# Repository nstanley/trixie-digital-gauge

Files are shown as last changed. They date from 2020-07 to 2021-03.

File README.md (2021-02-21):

# trixie-digital-gauge
A digital OBD-II gauge for my 2001 Audi TT, Trixie!

## Overview
I've wanted to do an On Board Diagnostics project for a while, just for the sake of seeing some of the data my car knows but I don't. I've deployed this to my project/fun car, a 2001 Audi TT.  
When the car is turned on, the Raspberry Pi is powered on and it runs the appropriate python script. The user can cycle through the available data via a rotary encoder. Once the car is powered off, the Raspberry Pi will shutdown automatically, waiting for the next ignition.

## Hardware
Most aftermarked car gauges come in a 52mm package, so that was my target for selecting a screen. There are probably screens that will fit in a 52mm diameter, however with the extra pins and mount points, I ended up with a 57mm sized gauge (57mm is the size of the climate control dials). 
 * For the screen, I chose Adafruit's [OLED Breakout Board - 16-bit Color 1.27" w/microSD holder](https://www.adafruit.com/product/1673), which is large enough to be easily visible and small enough to fit my 57mm gauge. 
 * For control, I chose a Raspberry Pi Zero. Running a Linux OS instead of directly on a board was just a faster way to get all my components together.
 * To interface to the car, I have a USB ELM327 
 * To cycle between PIDs, I'm using a rotary encoder
 * To power the board in the car, I'm using [Mausberry's 4AMP CAR SUPPLY / SWITCH](https://mausberry-circuits.myshopify.com/collections/frontpage/products/4amp-car-supply-switch). This is a pretty slick board that attaches to the car's 12V feeds, both constant and switched, to check if the car is on and send power accordingly

## Software
As a C/C++ guy, I chose Python for this project. Why? Primarily because there are tons of existing libraries out there to do what I need done. Those libraries primarily being [Adafruit's](https://learn.adafruit.com/adafruit-1-5-color-oled-breakout-board?view=all) to control their OLED and [python-OBD](https://python-obd.readthedocs.io/en/latest/) to interface with the ELM327 over USB.
The software is setup with a Model-View-Controller pattern. The controller `trixie.py` creates a model `trixie-model.py` to get the data from the ELM327. The controller then pipes that data to the view `trixie-view.py`, which manages the OLED to display the data. This decouples the logic so I can swap in different models or different views (see Future Work below) with ease.

## Setup
As I looked for the fastest way to boot a Raspberry Pi, I came across [DietPi](https://dietpi.com/). I'm always looking for different Linux distros, so I gave it a shot. 

### OS Setup
I used [DietPi's Raspberry Pi 32 bit image](https://dietpi.com/downloads/images/DietPi_RPi-ARMv6-Buster.7z) and [Balena's Etcher](https://www.balena.io/etcher/) software to flash an 8GB SD card. Before you install the SD card, you will need to edit the `/boot/config.txt` to enable SPI, as DietPi does not have an option to do that internally. Edit the SPI line as shown below
```
#-------SPI-------------
dtparam=spi=on
```
Once booted and logged in (I logged in as `root`), DietPi should ask you to configure your setup, which you can access via
```
dietpi-config
```
If your network wasn't setup on first boot, it will probably complain about trying to connect to the network. Use `DietPi-Config` to configure the network setup, then `Retry` so it can pull the latest updates. The setup will ask some questions, and eventually end on a page about installing additional software. You can just hit `<OK>` at the bottom, and confirm you want to start with a minimal image. Once finished, you can configure the following options for fast boot and our startup from `DietPi-Config`.
 * Advanced Options-> Time sync mode -> Custom. No need to sync the clock, the time sync requires internet to sync and we won't always have it in the car. And this will block the boot sequence
 * Network Options: Misc -> Boot Net Wait -> Disabled. 
 * AutoStart Options -> Custom. We will use a script to launch our app.

Now we just need `git` to grab the repo
```
sudo apt install git
```
We can now setup the software

### Software Setup
The first step would be to clone this repo
```
git clone https://github.com/nstanley/trixie-digital-gauge.git
cd trixie-digital-gauge
```
To get all the necessary libraries, you can use the `get-deps.sh` script
```
sudo bash get-deps.sh
```
This will install support packages used by the gauge. You should now be able to run the gauge
```
python3 code/trixie.py
```
If you don't have this wired in the car, it should attempt to connect to the car, fail 7 times, then run a simple demo. If you see `Demo: Connected!` and it is still running, then everything is installed and setup.

The final step is to setup the autostart script. I have setup a necessary script at `resources/autostart.sh`
```
cp resources/autostart.sh /var/lib/dietpi/dietpi-autostart/custom.sh
chmod 777 /var/lib/dietpi/dietpi-autostart/custom.sh
```
Final check - reboot and verify the same output as the initial test above, but from the start without any user interaction. The demo is set to run for a short time and then stop, which would send the script to the following `poweroff` command (assuming this was in a car, we shutdown once we exit the gauge).

### Hardware setup

### Future work
I came across an awesome [Hackster.io post](https://www.hackster.io/databus100/digital-speedometer-to-car-s-instrument-cluster-via-can-bus-66e273) about sending data to the existing LCD screen in the TT, as if it were the radio. The Hackster post describes a system with the "new" CAN interface, but I'm lucky enough to have the earlier interface described by the [inspiration for the post](https://github.com/derpston/Audi-radio-DIS-reader). I have parts on order to try to tap into that interface.

## Resources
 * https://en.wikipedia.org/wiki/OBD-II_PIDs
 * https://python-obd.readthedocs.io/en/latest/
 * https://github.com/guyc/py-gaugette
 * https://learn.adafruit.com/circuitpython-on-raspberrypi-linux/spi-sensors-devices
 * https://learn.adafruit.com/adafruit-1-5-color-oled-breakout-board?view=all
 * https://learn.adafruit.com/reading-a-analog-in-and-controlling-audio-volume-with-the-raspberry-pi?view=all
 * https://www.dafont.com/seven-segment.font

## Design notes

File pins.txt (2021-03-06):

        Pwr   - xx - 
              - xx - 
              - xx - Gnd
              - xx - 
Btn Gray      - xx - 
              - xx - 
Btn Purp      - xx - 
Btn Blue      - xx - 
              - xx - Scr Purp (R)
Scr Yllw (SI) - xx - 
              - xx - Scr Blue (DC)
Scr Gren (CL) - xx - scr Gray (OC/CE0)
              - xx - 
              - xx - 
              - xx - 
              - xx - 
              - xx - 
Btn Purp (B)  - xx - 
Btn Blue (A)  - xx - 
Btn Gray      - xx - 

+-----+-----+---------+------+---+---Pi 3---+---+------+---------+-----+-----+
 | BCM | wPi |   Name  | Mode | V | Physical | V | Mode | Name    | wPi | BCM |
 +-----+-----+---------+------+---+----++----+---+------+---------+-----+-----+
 |     |     |    3.3v |      |   |  1 || 2  |   |      | 5v      |     |     |
 |   2 |   8 |   SDA.1 | ALT0 | 1 |  3 || 4  |   |      | 5v      |     |     |
 |   3 |   9 |   SCL.1 | ALT0 | 1 |  5 || 6  |   |      | 0v      |     |     |
 |   4 |   7 | GPIO. 7 |   IN | 1 |  7 || 8  | 0 | IN   | TxD     | 15  | 14  |
 |     |     |      0v |      |   |  9 || 10 | 1 | IN   | RxD     | 16  | 15  |
 |  17 |   0 | GPIO. 0 |   IN | 0 | 11 || 12 | 0 | IN   | GPIO. 1 | 1   | 18  |
 |  27 |   2 | GPIO. 2 |   IN | 0 | 13 || 14 |   |      | 0v      |     |     |
 |  22 |   3 | GPIO. 3 |   IN | 0 | 15 || 16 | 0 | IN   | GPIO. 4 | 4   | 23  |
 |     |     |    3.3v |      |   | 17 || 18 | 0 | IN   | GPIO. 5 | 5   | 24  |
 |  10 |  12 |    MOSI | ALT0 | 0 | 19 || 20 |   |      | 0v      |     |     |
 |   9 |  13 |    MISO | ALT0 | 0 | 21 || 22 | 0 | IN   | GPIO. 6 | 6   | 25  |
 |  11 |  14 |    SCLK | ALT0 | 0 | 23 || 24 | 1 | OUT  | CE0     | 10  | 8   |
 |     |     |      0v |      |   | 25 || 26 | 1 | OUT  | CE1     | 11  | 7   |
 |   0 |  30 |   SDA.0 |   IN | 1 | 27 || 28 | 1 | IN   | SCL.0   | 31  | 1   |
 |   5 |  21 | GPIO.21 |   IN | 1 | 29 || 30 |   |      | 0v      |     |     |
 |   6 |  22 | GPIO.22 |   IN | 1 | 31 || 32 | 0 | IN   | GPIO.26 | 26  | 12  |
 |  13 |  23 | GPIO.23 |   IN | 0 | 33 || 34 |   |      | 0v      |     |     |
 |  19 |  24 | GPIO.24 |   IN | 0 | 35 || 36 | 0 | IN   | GPIO.27 | 27  | 16  |
 |  26 |  25 | GPIO.25 |   IN | 0 | 37 || 38 | 0 | IN   | GPIO.28 | 28  | 20  |
 |     |     |      0v |      |   | 39 || 40 | 0 | IN   | GPIO.29 | 29  | 21  |
 +-----+-----+---------+------+---+----++----+---+------+---------+-----+-----+
 | BCM | wPi |   Name  | Mode | V | Physical | V | Mode | Name    | wPi | BCM |
 +-----+-----+---------+------+---+---Pi 3---+---+------+---------+-----+-----+

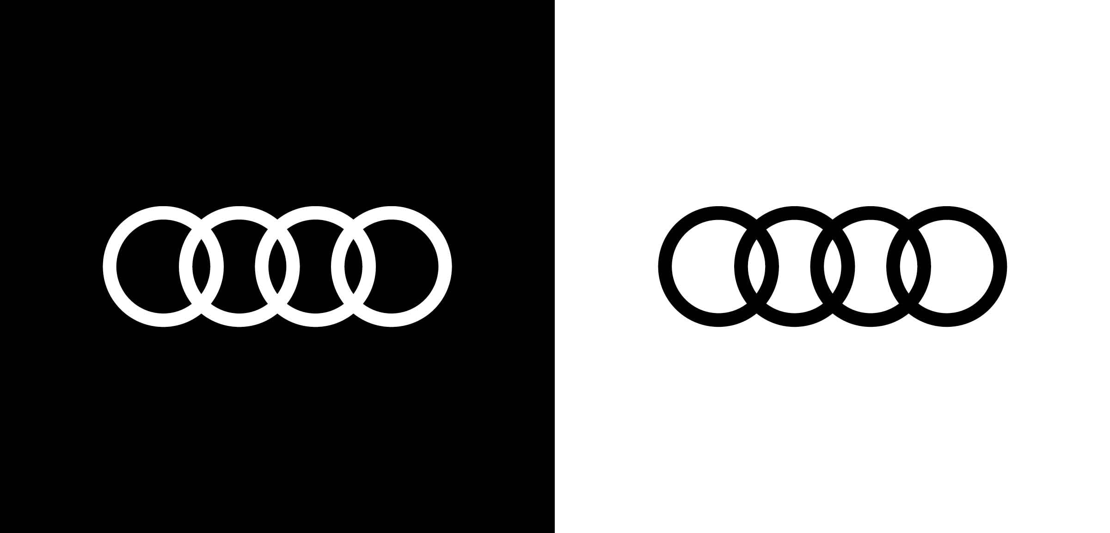
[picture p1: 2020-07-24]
resources/Audi_Brandplattform_Ringe_Content1.jpg

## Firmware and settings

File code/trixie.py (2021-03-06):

# Main program to run the OBD Gauge

import os
import time
import subprocess
import digitalio
import board
import gaugette.gpio
import gaugette.rotary_encoder
import gaugette.switch
import json
import enum

from trixie_view import TrixieView_OLED, TrixieView_DIS
from trixie_model import TrixieModel, TrixieModel_OBD, TrixieModel_Demo

# Configuration for CS and DC pins (these are PiTFT defaults):
cs_pin = digitalio.DigitalInOut(board.CE0)
dc_pin = digitalio.DigitalInOut(board.D25)
reset_pin = digitalio.DigitalInOut(board.D24)

# Config for display baudrate (default max is 24mhz):
BAUDRATE = 24000000

# Splash Image
BASE_DIR = os.path.dirname(os.path.dirname(os.path.abspath(__file__)))
splashFile = BASE_DIR + "/resources/audi_128x96-big-red.png"

# Rotary encoder pins (WiringPi numbering)
enc_A_pin = 23
enc_B_pin = 24
enc_btn_pin = 25

# Radio display pins (WiringPi numbering)
dis_clk_pin = 27
dis_data_pin = 28
dis_enable_pin = 29

class Mode(str, enum.Enum):
    ControlGauge = "ControlGauge"
    ControlRadio = "ControlRadio"
    ControlNone = "ControlNone"

class TrixieController():
    def __init__(self):
        # Setup VIEW
        self.viewGauge = TrixieView_OLED(cs_pin, dc_pin, reset_pin, BAUDRATE, splashFile)
        self.viewRadio = TrixieView_DIS(dis_clk_pin, dis_data_pin, dis_enable_pin, 1)
    
        # Setup MODEL
        self.modelDemo = TrixieModel_Demo()
        self.modelOBD = TrixieModel_OBD()
        self.model = self.modelOBD

        # Connect
        if (self.model.connect("/dev/ttyUSB0", 7)):
            self.demo = False
            print("Connected!")
        else:
            self.demo = True
            self.startTime = time.perf_counter()
            print("OBD Timeout, switch to DEMO MODE!")
            self.model = self.modelDemo
            self.model.connect("/dev/ttyAMA0", 7)

        # Setup list
        self.labels = ("Eng Load",
                       "Cool Tmp",
                       "S Fuel",
                       "L Fuel",
                       "RPM",
                       "Speed",
                       "Intake Tmp",
                       "MAF",
                       "Throttle")
        self.values = (self.model.getEngineLoad,
                       self.model.getEngineTemp,
                       self.model.getShortFuelTrim,
                       self.model.getLongFuelTrim,
                       self.model.getRPM,
                       self.model.getSpeed,
                       self.model.getIntakeTemp,
                       self.model.getMAF,
                       self.model.getThrottle)
        self.load()
        
        # Setup rotary encoder
        gpio = gaugette.gpio.GPIO()
        self.encoder = gaugette.rotary_encoder.RotaryEncoder(gpio, enc_A_pin, enc_B_pin, self.rotated)
        self.encoder.start()
        self.button = gaugette.switch.Switch(gpio, enc_btn_pin)
        self.button.enable_isr(gpio.EDGE_FALLING, self.pushed)

    def run(self):
        running = True
        while (running):
            try:
                self.viewGauge.showData(self.labels[self.gaugeIndex], str(self.values[self.gaugeIndex]()))
                if (self.radioIndex >= len(self.labels)):
                    self.viewRadio.showData("", "")
                else:
                    self.viewRadio.showData(self.labels[self.radioIndex], str(self.values[self.radioIndex]()))
                time.sleep(0.2)
            except:
                running = False

            # Only run the demo for 64s
            if self.demo:
                now = time.perf_counter()
                diff = now - self.startTime
                if (diff > 64):
                    running = False
        self.save()
        exit()
    
    # ISR for rotary encoder
    def rotated(self, direction):
        if (self.modeIndex == Mode.ControlGauge):
            self.gaugeIndex += direction
            if (self.gaugeIndex >= len(self.labels)):
                self.gaugeIndex = 0
            if (self.gaugeIndex < 0):
                self.gaugeIndex = len(self.labels) - 1
        elif (self.modeIndex == Mode.ControlRadio):
            self.radioIndex += direction
            if (self.radioIndex > len(self.labels)): # additional index for off
                self.radioIndex = 0
            if (self.radioIndex < 0):
                self.radioIndex = len(self.labels)

    def pushed(self):
        if (self.modeIndex == Mode.ControlGauge):
            self.modeIndex = Mode.ControlRadio
        elif (self.modeIndex == Mode.ControlRadio):
            self.modeIndex = Mode.ControlNone
        elif (self.modeIndex == Mode.ControlNone):
            self.modeIndex = Mode.ControlGauge

    def save(self):
        data = {}
        data['save'] = []
        data['save'].append(
            {
                'gaugeIndex': self.gaugeIndex,
                'radioIndex': self.radioIndex,
                'modeIndex': self.modeIndex
            }
        )
        with open('save.json', 'w') as filePtr:
            json.dump(data, filePtr)

    def load(self):
        try:
            with open('save.json', 'r') as filePtr:
                saveData = json.load(filePtr)
                for d in saveData['save']:
                    self.gaugeIndex = d['gaugeIndex']
                    self.radioIndex = d['radioIndex']
                    self.modeIndex = d['modeIndex']
        except:
            self.gaugeIndex = 0
            self.radioIndex = 0
            self.modeIndex = Mode.ControlNone

def main():
    print("Trixie Digital Gauge Startup!")
    gauge = TrixieController()
    gauge.run()

if __name__ == "__main__":
    main()

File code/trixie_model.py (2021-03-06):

import time
import random
import obd
from obd import OBDStatus
from obd import OBDCommand, Unit
from obd.protocols import ECU
from obd.utils import bytes_to_int

class TrixieModel():
    def __init__(self):
        print("baseclass")

    def getEngineLoad(self):
        return 0

    def getEngineTemp(self):
        return 0

    def getShortFuelTrim(self):
        return 0

    def getLongFuelTrim(self):
        return 0

    def getRPM(self):
        return 0
    def getSpeed(self):
        return 0

    def getIntakeTemp(self):
        return 0

    def getMAF(self):
        return 0

    def getThrottle(self):
        return 0

class TrixieModel_OBD(TrixieModel):
    def __init__(self):
        print("OBD: OBD model initialized")

    def connect(self, address, max_attempts):
        print("OBD: Attempting OBD-II connection...")
        self.connection = obd.OBD(address)
        attempts = 0
        # Attempt retries as necessary
        while (self.connection.status() != OBDStatus.CAR_CONNECTED and attempts < max_attempts):
            attempts += 1
            print("OBD: Attempting reconnect", attempts, "...")
            time.sleep(1)
            self.connection = obd.OBD(address)

        if (self.connection.status() != OBDStatus.CAR_CONNECTED):
            print("OBD: Could not connect after", attempts, "retries!")
            self.connection.close()
            return False
        else:
            print("OBD: Connected!")
            return True

    def getEngineLoad(self):
        retrun = self.connection.query(obd.commands.ENGINE_LOAD)
        return '{:d}'.format(int(retrun.value.magnitude))

    def getEngineTemp(self):
        retrun = self.connection.query(obd.commands.COOLANT_TEMP)
        return '{:d}'.format(int(retrun.value.to('degF').magnitude))

    def getShortFuelTrim(self):
        retrun = self.connection.query(obd.commands.SHORT_FUEL_TRIM_1)
        return '{:.2f}'.format(retrun.value.magnitude)

    def getLongFuelTrim(self):
        retrun = self.connection.query(obd.commands.LONG_FUEL_TRIM_1)
        return '{:.2f}'.format(retrun.value.magnitude)

    def getRPM(self):
        retrun = self.connection.query(obd.commands.RPM)
        return '{:d}'.format(int(retrun.value.magnitude))

    def getSpeed(self):
        retrun = self.connection.query(obd.commands.SPEED)
        return '{:d}'.format(int(retrun.value.to('mph').magnitude))

    def getIntakeTemp(self):
        retrun = self.connection.query(obd.commands.INTAKE_TEMP)
        return '{:d}'.format(int(retrun.value.to('degF').magnitude))

    def getMAF(self):
        retrun = self.connection.query(obd.commands.MAF)
        return '{:.1f}'.format(retrun.value.magnitude)

    def getThrottle(self):
        retrun = self.connection.query(obd.commands.THROTTLE_POS)
        return '{:d}'.format(int(retrun.value.magnitude))

class TrixieModel_Demo(TrixieModel):
    def __init__(self):
        print("Demo: Demo model initialized!")
        self.engine_load = 0
        self.engine_temp = 0
        self.short_fuel = 0
        self.long_fuel = 0
        self.RPM = 0
        self.speed = 0
        self.intake_temp = 0
        self.MAF = 0
        self.throttle = 0

    def connect(self, address, max_attempts):
        print("Demo: Attempting OBD-II connection...")
        time.sleep(1.0)
        print("Demo: Connected!")
        return True

    def getEngineLoad(self):
        if (self.engine_load > 50):
            new_load = self.engine_load + random.randint(-7, 3)
        else:
            new_load = self.engine_load + random.randint(-3, 7)
            
        if (new_load < 0):
            new_load = 0
        if (new_load > 100):
            new_load = 100

        self.engine_load = new_load
        return self.engine_load

    def getEngineTemp(self):
        return self.engine_temp

    def getShortFuelTrim(self):
        return self.short_fuel

    def getLongFuelTrim(self):
        return self.long_fuel

    def getRPM(self):
        return self.RPM

    def getSpeed(self):
        return self.speed

    def getIntakeTemp(self):
        return self.intake_temp

    def getMAF(self):
        return self.MAF

    def getThrottle(self):
        return self.throttle

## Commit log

2020-07-09 some initial setup and notes
    [trixie-digital-gauge.fzz]
2020-07-13 add mausberry-switch submodule
2020-07-27 some screen demo
    [trixie-digital-gauge.fzz]
2020-07-27 some encoder testing
2020-08-10 setup rotary encoder + units
2020-09-13 update notes
    [Road Speed in Each Gear.ods]
2020-11-14 pin update
2021-02-21 add mausberry refs and a demo timer
2021-02-25 add modes and rename view
    [trixie-digital-gauge.fzz]
2021-02-25 import switch
2021-02-26 setup an arduino sketch to test radio dis
2021-03-02 get DIS working on arduino (inverted logic)
    [dis.ino]
2021-03-02 update python dis to match arduino
2021-03-02 add single line support (for those of us with broken screens)
    [dis.py]
2021-03-05 add print statements
2021-03-05 try wiring pi
2021-03-05 remove prints (stable clock)
